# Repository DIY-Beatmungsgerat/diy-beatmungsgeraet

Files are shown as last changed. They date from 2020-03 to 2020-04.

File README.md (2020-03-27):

<p align="center">
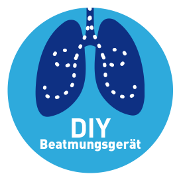
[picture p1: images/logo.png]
  
</p>

# DIY-Beatmungsgerät

DIY Beatmungsgerät basierend auf einem Open Source und Open Hardware Entwurf. Der Grundstein wurde während des [#WirvsVirusHackathon](https://wirvsvirushackathon.org/) im März 2020 gelegt.

Momentan sind wir noch mitten im Endspurt des Wochenendes, daher wird es noch eine Weile dauern, bis dieses Repository tatsächlich mit unseren Inhalten gefüllt ist. Derzeit pflegen wir unsere Inhalte noch intern ein!

Das 3D-Modell des Beatmungsgerätes basiert auf Iteration #6 des Open Source Ventilator (OSV) Project, in gitlab unter https://gitlab.com/open-source-ventilator/OpenLung zu finden.

(eventuell wechseln wir die Dokumentation hier auf Englisch)

## Repository-Struktur

Wir arbeiten an verschiedensten Themen. Zum einen etwa an der Weiterentwicklung des Beatmungsgerätes, als auch an dessen Ansteuerung bzw. Regelung und weiterer Sensorik.

* [/ hardware / mass-airflow-model /](/hardware/mass-airflow-model/): Modelle für die Röhre eines Masseflusssensors
* [/ hardware / ventilator-model/](/hardware/ventilator-model/): das weiterentwickelte Modell des Beatmungsgerätes
* [/ software / mass-airflow-sensor / controller-software/](/software/mass-airflow-sensor/controller-software/): die Software, die auf der Plattform läuft, um den Luftmassesensor auszulesen (Mock-Up)
* [/ software / mass-airflow-sensor / sensor-software/](/software/mass-airflow-sensor/sensor-software/): die Software, die auf dem Sensor selbst läuft, der Luftmassesensor-Daten bereitstellt (Mock-Up)
* [/ software / ventilator-control/](/software/ventilator-control/): die Software für die Steuerungs-Plattform des Beatmungsgerätes

# Weiterführende Links
* [Homepage des WirvsVirus Hackathon](https://wirvsvirushackathon.org/)
* [Projekt-Vorstellung auf devpost.com](https://devpost.com/software/diy-beatmungsgerat)
* [Projekt-Vorstellung auf YouTube](https://www.youtube.com/watch?v=DzOd6LIBdXI)
* https://gitlab.com/open-source-ventilator/OpenLung

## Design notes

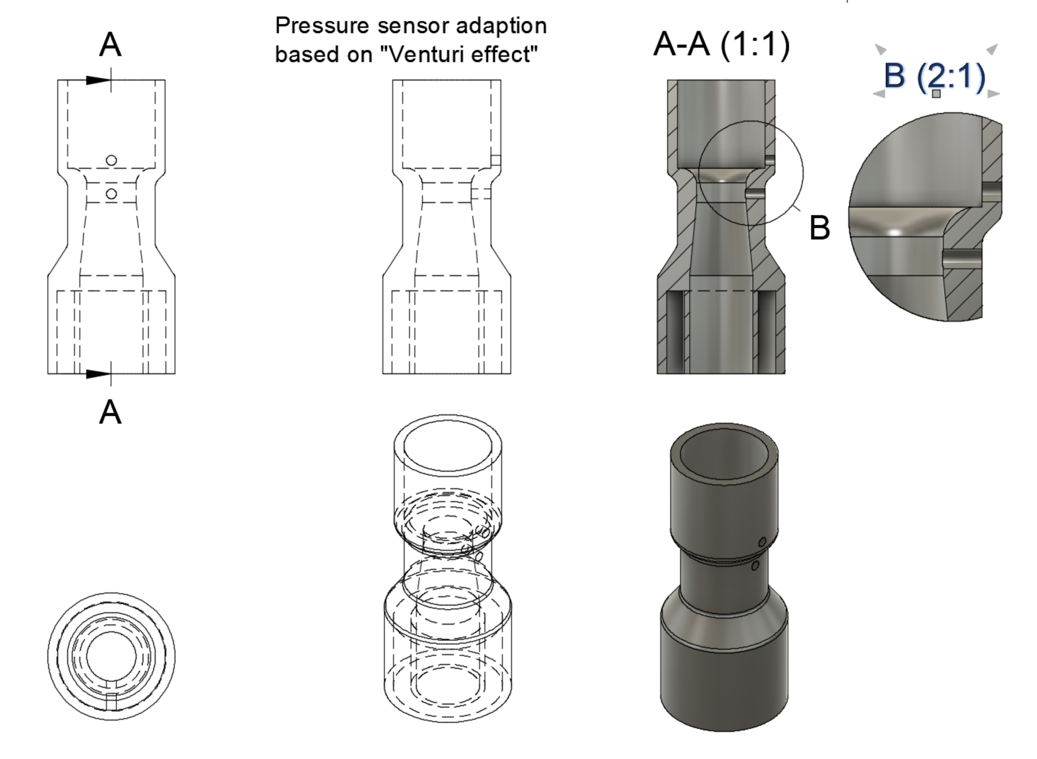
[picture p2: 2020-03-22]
images/mass_airflow_adapter_drawing.png

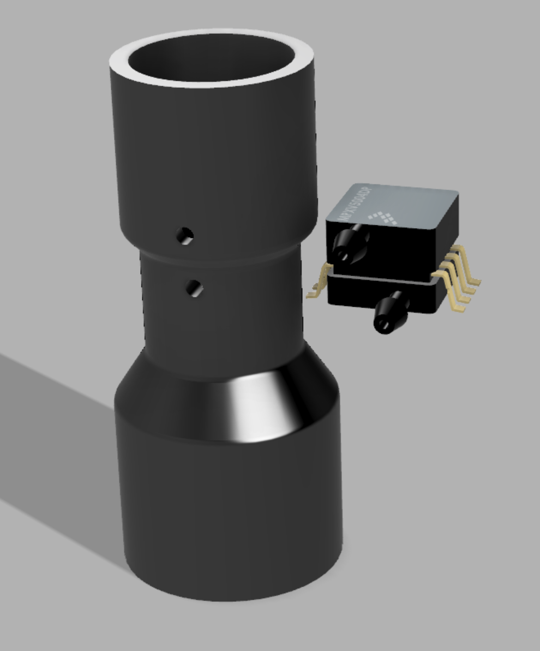
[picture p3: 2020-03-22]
images/mass_airflow_adapter_with_sensor.png

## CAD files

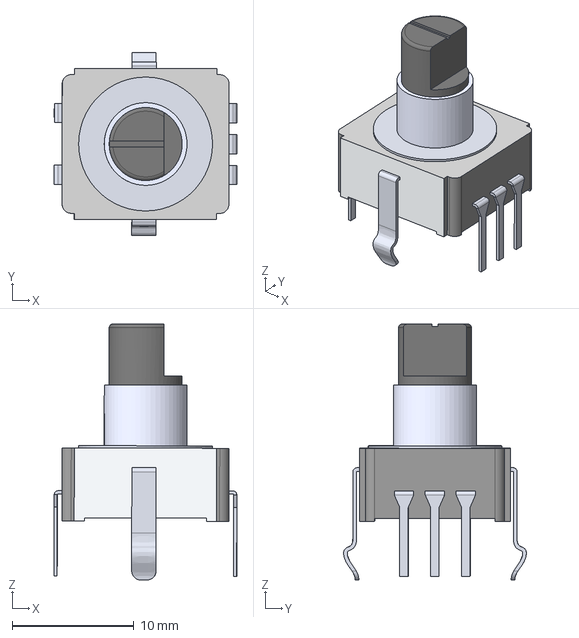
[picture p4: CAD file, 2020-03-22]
hardware/ventilator-model/Encoder v2.step
15.0 x 15.0 x 21.0 mm

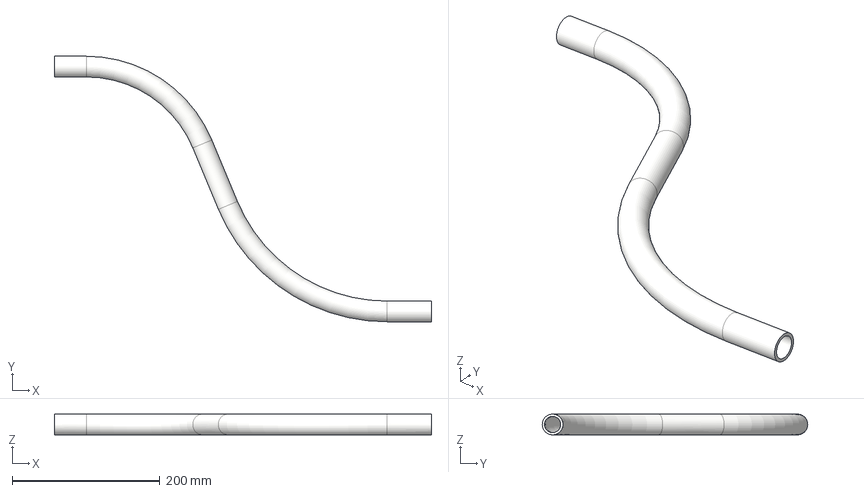
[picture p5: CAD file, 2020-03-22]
hardware/ventilator-model/Schlauch v5.step
510.0 x 359.2 x 28.0 mm

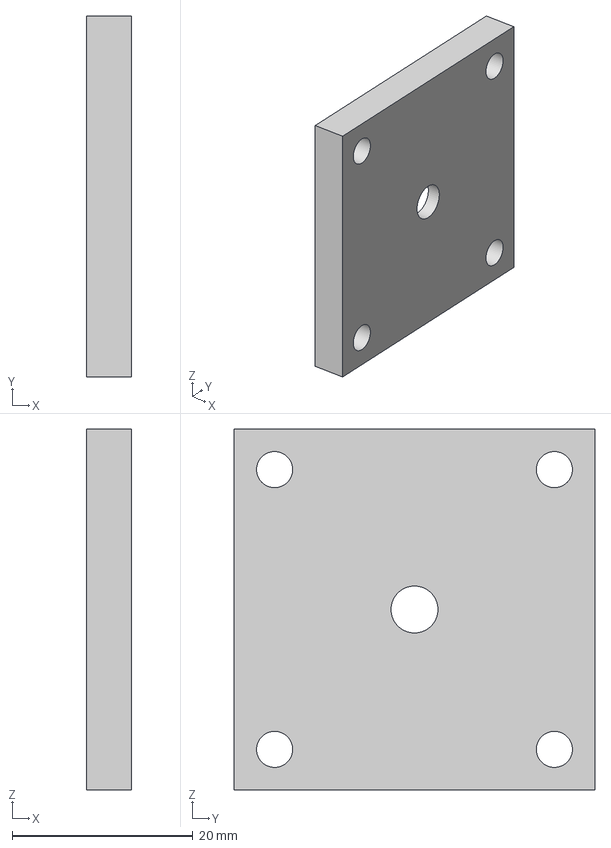
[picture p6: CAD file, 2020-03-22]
hardware/ventilator-model/Encoderplatte v2.step
5.00 x 40.0 x 40.0 mm

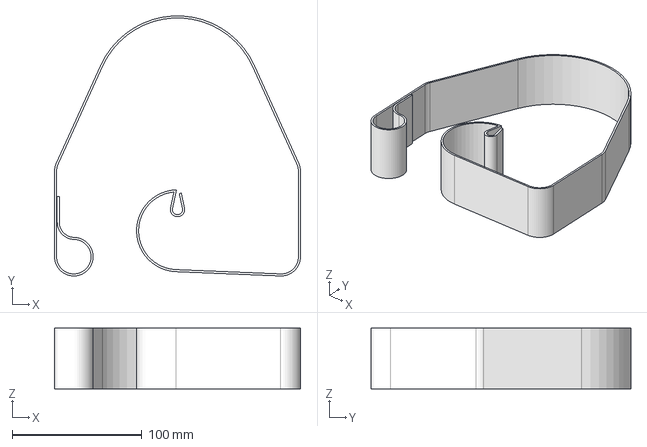
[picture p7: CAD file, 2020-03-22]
hardware/ventilator-model/Belt v1.step
189.8 x 200.6 x 47.0 mm

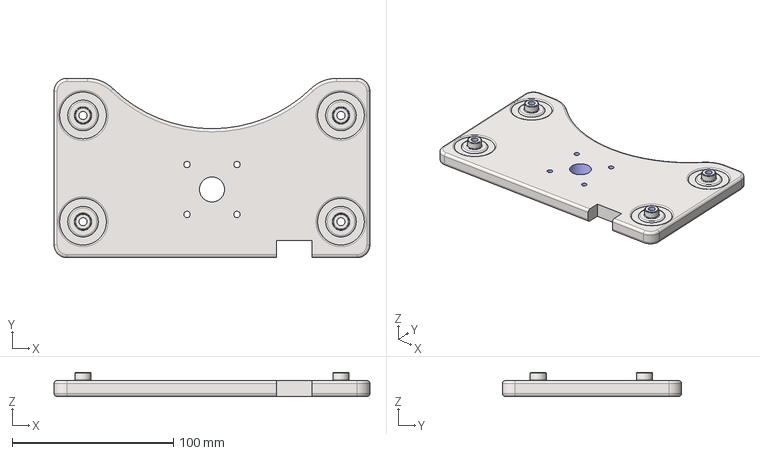
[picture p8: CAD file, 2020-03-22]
hardware/ventilator-model/HousingMotor v2.step
196.0 x 111.2 x 15.0 mm

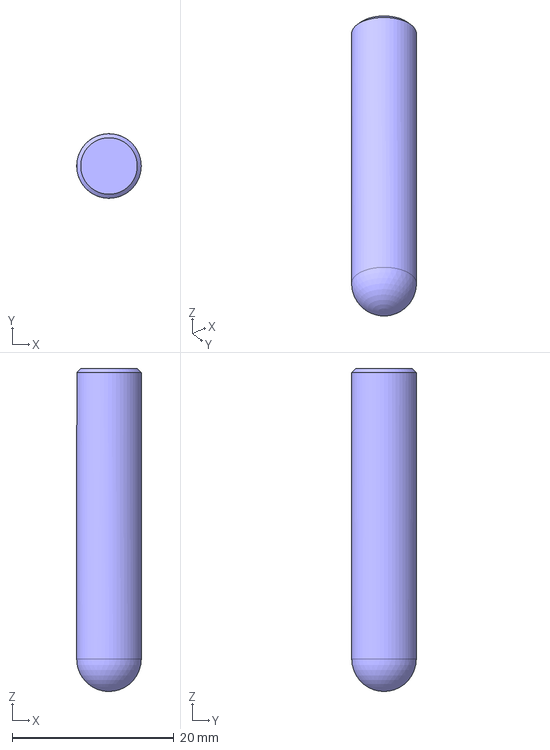
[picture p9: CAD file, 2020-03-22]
hardware/ventilator-model/Pin v1.step
8.00 x 8.00 x 40.0 mm

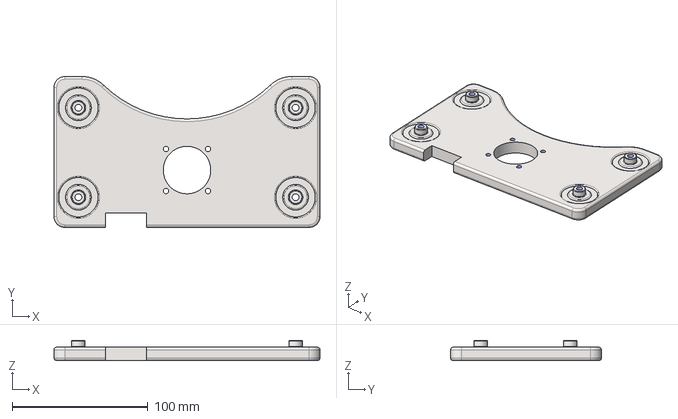
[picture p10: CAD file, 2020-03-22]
hardware/ventilator-model/HousingElectrical v3.step
196.0 x 111.2 x 15.0 mm

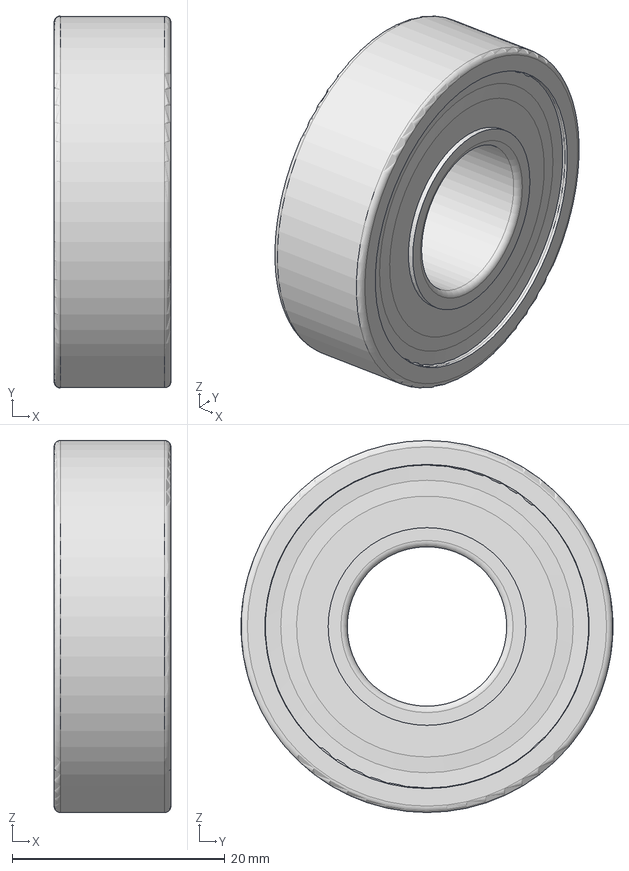
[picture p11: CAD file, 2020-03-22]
hardware/ventilator-model/Rillenkugellager_15x35x11 v1.step
11.0 x 35.0 x 35.0 mm
_6202-2RSL_PART1
_6202-2RSL_PART2
_6202-2RSL_PART3 x 8
_6202-2RSL_PART4 x 8

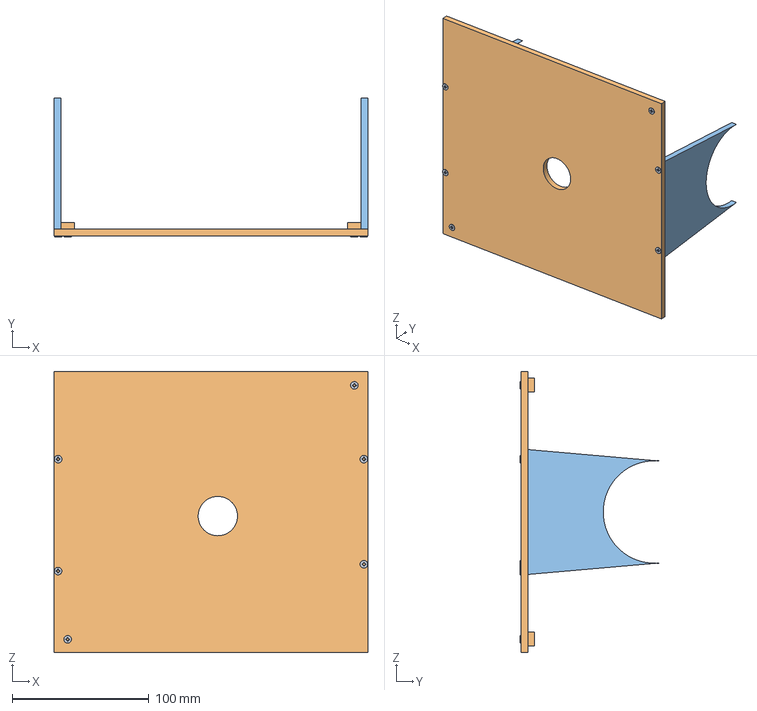
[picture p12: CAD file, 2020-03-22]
hardware/ventilator-model/Deckel v6.step
230.0 x 101.6 x 206.0 mm
DIN 7997 H - d 3 x l 10 - St x 6

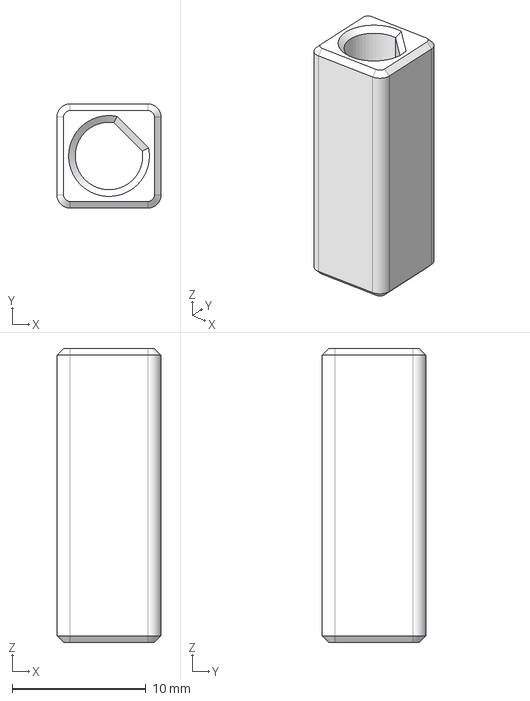
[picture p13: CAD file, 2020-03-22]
hardware/ventilator-model/ShaftAdaptor v1.step
7.80 x 7.80 x 22.0 mm

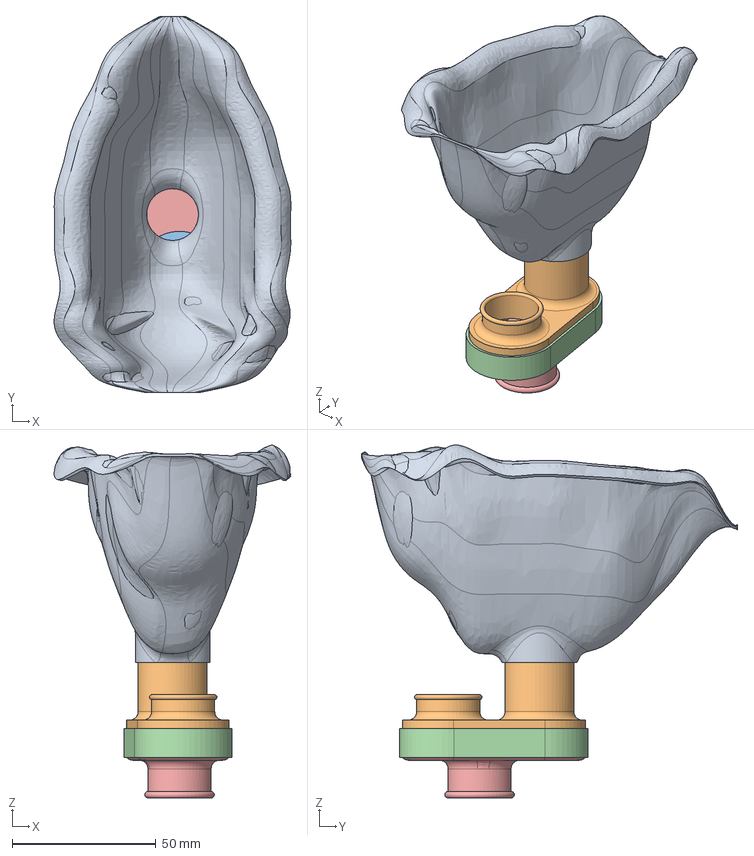
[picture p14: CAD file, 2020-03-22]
hardware/ventilator-model/Maske v1.step
82.5 x 131.0 x 123.0 mm
medical mask
BODY VALVE
flap
BODY VALVE 1

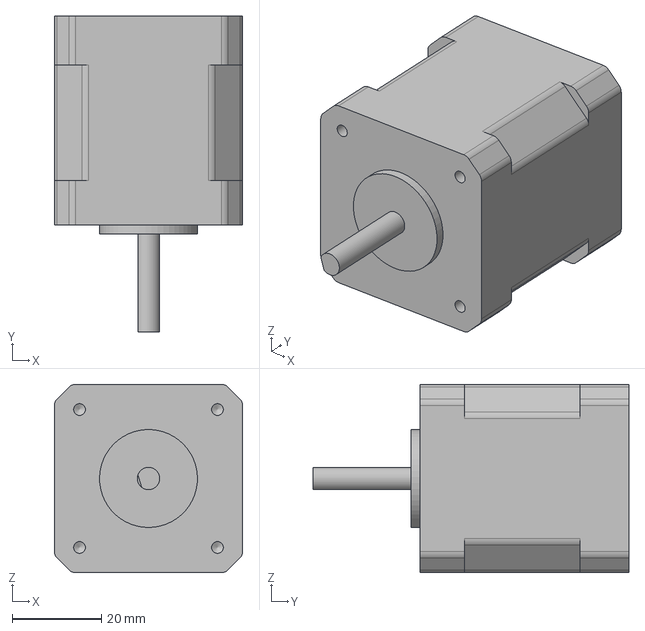
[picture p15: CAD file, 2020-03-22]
hardware/ventilator-model/StepMotor_Nema17 v1.step
42.3 x 71.0 x 42.3 mm

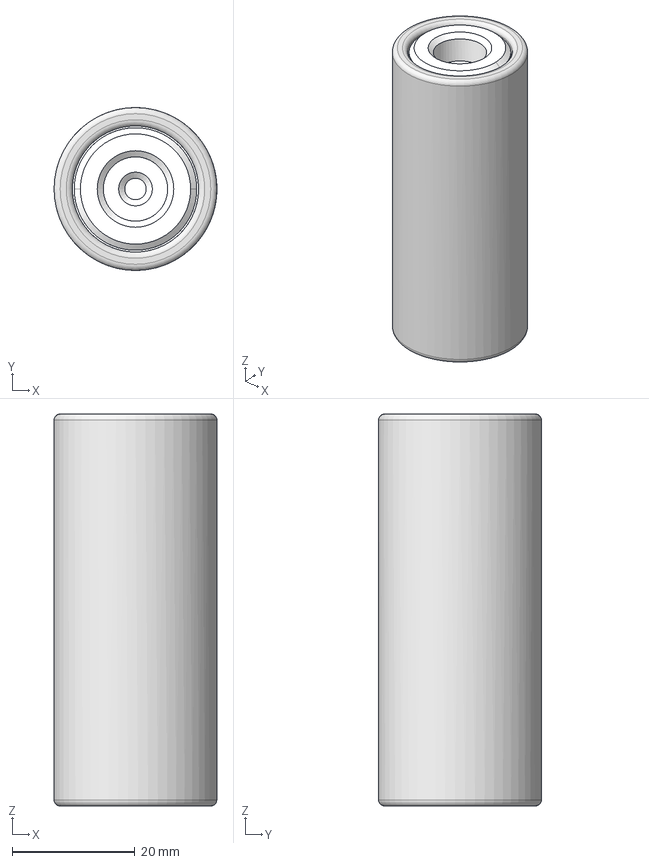
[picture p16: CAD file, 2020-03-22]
hardware/ventilator-model/Spacer v3.step
26.6 x 26.6 x 64.0 mm

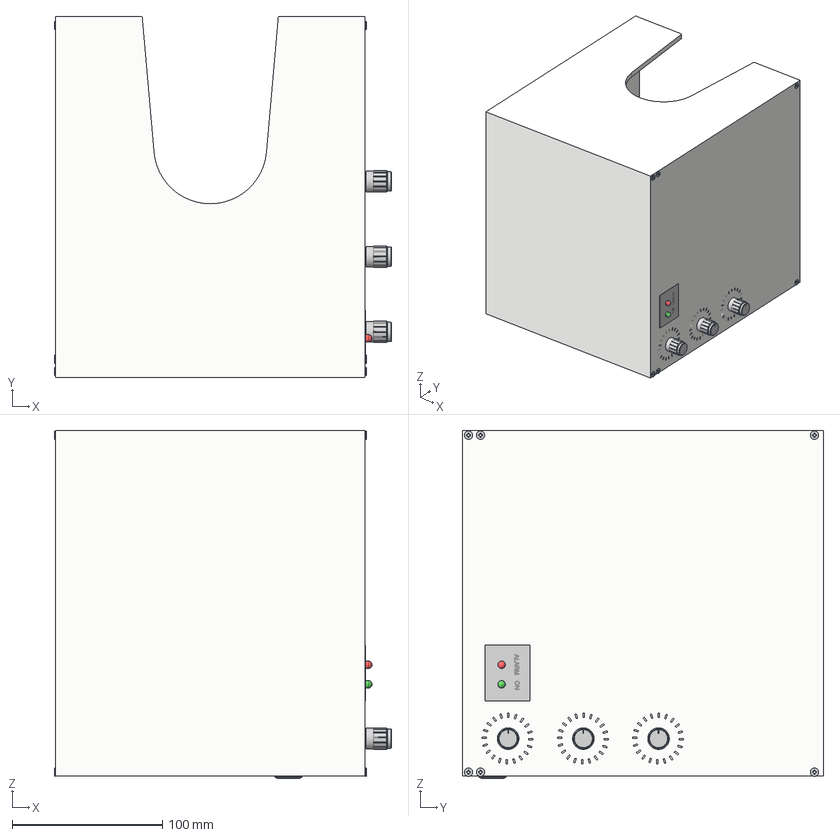
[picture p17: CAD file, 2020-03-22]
hardware/ventilator-model/Gehaeuse v31.step
224.4 x 240.0 x 231.7 mm
DIN 7997 H - d 3 x l 10 - St x 12
Poti x 3
Pot Knob x 3
ONOFFswitch
LED 5mm Red
LED 5mm Green

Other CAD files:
hardware/ventilator-model/Roller v2.step
hardware/ventilator-model/DIN7049-ST4 v1.step
hardware/mass-airflow-model/MPXV5004DP_3D.f3d
hardware/mass-airflow-model/mass_airflow_tube.f3d

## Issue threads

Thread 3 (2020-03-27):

Aktuelles Riemen-Design verursacht Drehung des / Reibung am BVM

joernhees, 2020-03-27:
Momentan sieht das Design so aus und wird entweder zu einer Drehung des BVMs oder viel Reibung und schnellem Verschleiß an diesem führen

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

Mein Vorschlag wäre das Design leicht zu verändern, indem der Riemen auch auf der anderen Seite um den Roller gelegt wird:
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

Auf die Weise wird der Riemen oben nur angezogen und rollt den BVM nicht mehr hin und her.

Bei der Änderung würde ich die Einschnitte im Roller für die Riemen-Enden auch gleich nicht so tief machen, damit er stabiler wird.

Leider konnte ich die step-files nicht einfach anpassen, daher hier nur als Konzept.

FelixThe, 2020-03-28:
Hört sich sinnvoll an

mechprof, 2020-03-30:
Hallo Zusammen,

ich bin Mechanik Entwickler und im Automobilbereich tätig. Ich habe am WE Euer Projekt entdeckt, unter anderem auch das Thema hier. Ich finde die Idee mit dem Riemen super genial. Die Abmessungen im CAD entsprechen fast genau den üblichen eines Anschnallgurtes im Auto. Das ist eine super Idee, Anschnallgurte sind sehr robust und weltweit verfügbar und völlig überdiemensioniert. Dh. die halten ewig.

Wenn Ihr offen seit, würde ich gerne einen optimierten Vorschlag als step hochladen. Was haltet Ihr von einem parallelen Verzeichnis. Seit Ihr damit einverstanden?

meine Optimierungsaspekte:

- die Antriebsrolle kann verkleinert werden => Ziel d=16mm, da doppelte Aufwicklung 16*pi*2 je Umdrehung. Achtung: 1,5 bis 2 Umdrehungen sollten minimum immer drauf sein. Da Archimedische Spirale wird d je Umdrehung 4 Gurtlagen dicker.
- höhere Teileintegration
- reduzierte Teile Zahl => Fertigungsaufwand / -kosten => Teile die es nicht gibt gehen nicht kaputt
- geringeres 3d print volumen => weniger Bauzeit
- Robustheit a) Teile b) Montage c) Funktion
- Trennung der Bauräume:
   - mechanische Komponenten (beweglich)
   - elektromechanische Komponenten (Motor)
   - elektrische Komponenten (Platine, Poti, LEDs, ...) => Ziel: staubfrei, Druck-/Feuchteausgleich

Falls jemand die Software Apis zur Verfügung hat, ich bin gerne bereit mit der Person eine FMEA aufzusetzen.

Anregungen:
   - Positionsmarkierungen auf Gurt (weisse Streifen, ein breiter Streifen als Referenz irgendwo in der Mitte), damit Entfall elektromechanisches Bauteil Encoder => Kontaktlose, verschleissfreie Positionserkennung. Können mit weissem Edding aufgemalt werden, Mit Laser ausgedruckt und auf Gurt genäht oder geklebt werden, wie auch immer....

Bitte:
Dies ist meine erste Github Benutzung. Sagt mir einfach was ich besser machen soll. Gebt mir einen Link wo es kurz und knapp schon steht. Ich habe einfach keine Ahnung.
  -

mechprof, 2020-03-30:
Hier ist mein aktueller Arbeitsstand in Bildern.

erreichte Ziele:
- alles auf einer Platine integriert: nur noch Motor und on/off Schalter mit Kabel
- Funktionen siehe Screenshot Stückliste

Frage:
- wofür braucht es den Massenstromsensor?
- das zugeführte Volumen ergibt sich aus p*v=R*T, wobei p und T via BME680 gemessen werden und v mit dem displacement korreliert und nach experimenteller Feststellung des Zusammenhangs gut ermittelt werden kann.

Es wäre sehr nett, wenn wir hier im Dialog weiter kämen. Ich hoffe anhand der Bilder wird klar, dass ich hier etwas beitragen kann.

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

mechprof, 2020-04-01:
**OK, verstanden, dass Projekt hier scheint tot zu sein.
Falls jemand weiter machen möchte, einfach melden.

Schlecht ist die Idee nicht.**

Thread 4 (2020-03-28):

Möglich Bewegung an den Schläuchen kann zu Abnutzung führen / Potential wear on hoses could lead to wear

FelixThe, 2020-03-28:
Im aktuellen Konzept wird der Beatmungsbeutel nur von einer Seite gedrückt (links). Dies kann zu einer Bewegung an den Schläuchen führen. Was haltet ihr davon, den Beutel von zwei Seiten zu drücken (rechts)? Dadurch würden sich die Schläuche weniger relativ zum Gehäuse bewegen.

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

mattheiss2020, 2020-03-28:
It looks like a nice solution, but I just remember my physics class at school and I think that we would need quite a strong motor to be able to squeeze the Ambu bag? Can anybody calculate that?

FelixThe, 2020-03-28:
Yes, you are right! It would need higher forces to squeeze the bag. I will think about a different solution for squeezing the bag from two sides.

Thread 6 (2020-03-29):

Abgleich mit MIT-Projekt

aKzenT, 2020-03-29:
https://e-vent.mit.edu/

Möglicherweise kann man sich von dort ja die ein oder andere Idee abschauen oder sich mit dem Team dort vernetzen, wenn noch nicht geschehen.

Heavy02011, 2020-03-30:
Vielen Dank, ja wir pflegen eine Liste der weiteren Projekte und ich werde ihm Team vorschlagen, dass sich darum jemand kümmert.

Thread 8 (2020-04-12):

Add GitHub workflow to validate code compilation in CI

synergiator, 2020-04-12:
Using for example Arduino CLI, it's possible to validate code compilation online without having the actual board.

See also:

https://codeblog.dotsandbrackets.com/gitlab-ci-esp32-arduino/

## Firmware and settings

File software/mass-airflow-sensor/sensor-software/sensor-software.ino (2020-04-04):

#include <Wire.h>
#include "crc8.h"

// Test setup:
//   Arduino Nano pin asssignment:
//     I2C SDA:      A4
//     I2C SCL:      A5
//     Analog input: A0
//     Real-time supervision pin: A3
//     Interrupt supervision pin: A2

/* Mapping of the analog input pin, define alias here */
#define ANALOG_INPUT_PIN      (A0)

/* Mapping of the digital output pin for real-time supervision, define alias here */
#define RT_SUPERVISION_PIN    (A3)

/* Mapping of the digital output pin for interrupt supervision, define alias here */
#define INT_SUPERVISION_PIN   (A2)

//#define DEBUG
#ifdef DEBUG
    #define debugPrint    Serial.print
    #define debugPrintln  Serial.println
#else
    #define debugPrint    
    #define debugPrintln  
#endif

/* Definition of sensor loop interval and loop delay,
 * i.e. how often to read the ANALOG_INPUT_PIN in order to get a new measurement from sensor;
 * the value is given in milliseconds.
 * current setting: approx. every 10 ms (i.e. at a rate of 100 Hz).
 * Note: This is not exact as the UART serial output will take some of that time, 
 *       plus conversions and interrupt overhead, plus loop overhead.
 *       When DEBUG output is active, it takes about 2 ms per cycle.
 *       Caution: The interrupt overhead is not subtracted automatically.
 */
#define SENSOR_LOOP_INTERVAL (10u)
#ifdef DEBUG
    #define SENSOR_LOOP_DELAY (SENSOR_LOOP_INTERVAL - (2u))
#else
    #define SENSOR_LOOP_DELAY (SENSOR_LOOP_INTERVAL)
#endif

/* Definition of sensor modes, i.e. what values will be return upon Wire transmit request event */
enum eSensorMode { SENSOR_MODE_NONE = 0, SENSOR_MODE_MEASURE, SENSOR_MODE_SERIALNO };

/* define the address of the sensor on the I2C bus;
 * TODO/FIXME: decide address to be used via GPIO input pin during setup()
 */
uint8_t g_nDeviceAddress = 64;

/* Initialize global variables */
//volatile int g_nConversionValue = 0; /* digital value for sensor's analog input */
volatile eSensorMode g_eMode = SENSOR_MODE_NONE; /* sensor mode start with 'NONE' */

volatile int16_t g_nDiffPressure = 0;

void setup()
{
    Serial.begin(230400);         // start serial for debug output

    Wire.begin(g_nDeviceAddress); // join i2c bus with address <g_nDeviceAddress>
    Wire.onReceive(receiveEvent); // register event handler for Rx
    Wire.onRequest(transmitRequestEvent); // register event handler for Tx request

#ifdef RT_SUPERVISION_PIN
    pinMode(RT_SUPERVISION_PIN, OUTPUT);
#endif
#ifdef INT_SUPERVISION_PIN
    pinMode(INT_SUPERVISION_PIN, OUTPUT);
#endif

#ifdef DEBUG
    Serial.println("Debug mode active.");
#else
    Serial.println("Debug mode inactive, no more output on serial.");
#endif
}

void loop()
{
    static int nConversionValue = 0;

#ifdef RT_SUPERVISION_PIN
    digitalWrite(RT_SUPERVISION_PIN, HIGH);
#endif
    
    nConversionValue = analogRead(ANALOG_INPUT_PIN);

    if( SENSOR_MODE_MEASURE == g_eMode )
    {
        debugPrint("[*] "); /* in measuring mode */
    }
    else
    {
        debugPrint("[ ] "); /* not in measuring mode */
    }

    // Debug output the sensor's reading (conversion valie)
    debugPrint("Sensor value: ");

    debugPrint(nConversionValue); // raw reading
    debugPrint(" counts, ");

    debugPrint( countsToMillivolts(nConversionValue) );
    debugPrint(" mV, ");

    float fPressure = millivoltsToMillimetersWater( countsToMillivolts( nConversionValue ) );
    debugPrint( fPressure );
    debugPrint(" mmH2O, ");

    g_nDiffPressure = ((int16_t)fPressure) << 2; /* the two least-significant bits are always zero */
    debugPrint( g_nDiffPressure );
    debugPrintln(" mmH2O*4");

    /* TODO/FIXME: add conversion from difference pressure to volume flow */

#ifdef RT_SUPERVISION_PIN
    digitalWrite(RT_SUPERVISION_PIN, LOW);
#endif

    /* Wait until next cyclic measurement is made */
    delay(SENSOR_LOOP_DELAY);
}

crc_t calcCrc(const unsigned char *pData, size_t nDataLen)
{
    crc_t nCrc = crc_init();
    nCrc = crc_update(nCrc, pData, nDataLen);
    nCrc = crc_finalize(nCrc);

    return nCrc;
}

/* Parse received command and switch sensor's state */
void receiveEvent(int nBytes)
{
    char sHexBuf[11]; /* string buffer for debug output via UART */
    uint8_t cCmdBytes[2]; /* command buffer (a command is 16 bit wide, or 2 bytes) */
    int nRxCount = 0;

#ifdef INT_SUPERVISION_PIN
    digitalWrite(INT_SUPERVISION_PIN, HIGH);
#endif

    debugPrint("Rx (");
    debugPrint(nBytes);
    debugPrint(" bytes): ");
    while(0 < Wire.available())   // loop through all but the last
    {
        uint8_t cRxByte = Wire.read(); /* receive byte as a character */

        /* store first two bytes in command buffer */
        if( nRxCount < 2 )
        {
            cCmdBytes[nRxCount] = cRxByte;
        }
        
        nRxCount++;

        /* print every byte as two hex digits with prefix '0x', NULL-terminate the string */
        sprintf(sHexBuf, "0x%02X ", cRxByte);
        sHexBuf[5] = 0;
        debugPrint(sHexBuf);
    }
    debugPrintln("");

    if( nRxCount < 2 )
    {
#ifdef INT_SUPERVISION_PIN
        digitalWrite(INT_SUPERVISION_PIN, LOW);
#endif
        return;
    }

    if( nRxCount != nBytes )
    {
        debugPrint("[DEBUG] Message length does not match (Rx count: ");
        debugPrint(nRxCount);
        debugPrint("; Message length: ");
        debugPrint(nBytes);
        debugPrintln(")");
        g_eMode = SENSOR_MODE_NONE;
#ifdef INT_SUPERVISION_PIN
        digitalWrite(INT_SUPERVISION_PIN, LOW);
#endif
        return;
    }

    if( 0x10 == cCmdBytes[0] && 0x00 == cCmdBytes[1] )
    {
        debugPrintln("Rx'ed 'start measurement' command");
        g_eMode = SENSOR_MODE_MEASURE;
    }
    else if( 0x31 == cCmdBytes[0] && 0xAE == cCmdBytes[1] )
    {
        debugPrintln("Rx'ed 'read serial number' command");
        g_eMode = SENSOR_MODE_SERIALNO;
    }
    else
    {
        debugPrintln("Rx'ed unknown command: ");
        sprintf(sHexBuf, "0x%02X 0x%02X ", cCmdBytes[0], cCmdBytes[1]);
        sHexBuf[10] = 0;
        debugPrint(sHexBuf);
        
        debugPrintln("(ignored)");
    }

#ifdef INT_SUPERVISION_PIN
        digitalWrite(INT_SUPERVISION_PIN, LOW);
#endif
}

/* Transmit data dependent on current sensor state */
void transmitRequestEvent(void)
{
#ifdef INT_SUPERVISION_PIN
    digitalWrite(INT_SUPERVISION_PIN, HIGH);
#endif

    debugPrintln("Tx request");

    switch( g_eMode )
    {
        case SENSOR_MODE_MEASURE:
            /* TODO/FIXME: add true measurement data and add CRC */
            debugPrintln("Tx measurement");
            char sMeas[2];
            //sMeas[0] = 'F';
            //sMeas[1] = 'L';
            sMeas[0] = (uint8_t)( (g_nDiffPressure & 0xFF00) >> 8 );
            sMeas[1] = (uint8_t)(g_nDiffPressure & 0xFF);
            Wire.write((char)sMeas[0]);
            Wire.write((char)sMeas[1]);
            Wire.write((char)calcCrc(&sMeas[0], 2) );
            break;
        case SENSOR_MODE_SERIALNO:
            char sSerNo[4];
            sSerNo[0] = 'S';
            sSerNo[1] = 'R';
            sSerNo[2] = 'N';
            sSerNo[3] = 'O';
            debugPrintln("Tx serialno");
            Wire.write((char)sSerNo[0]);
            Wire.write((char)sSerNo[1]);
            Wire.write((char)calcCrc(&sSerNo[0], 2) );
            Wire.write((char)sSerNo[2]);
            Wire.write((char)sSerNo[3]);
            Wire.write((char)calcCrc(&sSerNo[2], 2) );
            break;
        case SENSOR_MODE_NONE:
        default:
            debugPrintln("Tx nothing (controller will read 0xFF)");
            break;
    }

#ifdef INT_SUPERVISION_PIN
        digitalWrite(INT_SUPERVISION_PIN, LOW);
#endif
}

float countsToMillivolts(int nCounts)
{
    // For the Arduino Uno, its a 10 bit unsgined value (i.e. a range of 0..1023).
    // Its measurement range is from 0..5 volts.
    // This yields a resolution between readings of: 5 volts / 1024 units or approx. 4.9 mV per LSB
    return nCounts * 4.882813f;
}

float millivoltsToMillimetersWater(float fMillivolts)
{
    // for now, assume a linear transfer function of the sensor,
    // e.g. V_out = 0.6 V/kPa * dP + 0.6 V
    //         dP = (V_out - 0.6 V) / 0.6 V/kPa 
    //            = (V_out - 0.6 V) * 1.667 kPa/V
    //            = (V_out - 600 mV) * (1.667*100 mmH2O) / 1000 mV // 1 kPa ~ approx. 100 mmH2O

    float fPressure = (fMillivolts - 600.0f) * 0.1666666667f;

    // sanity check: no negative pressure value
    fPressure = (fPressure < 0.0f) ? 0.0f : fPressure;
    
    return fPressure;
}

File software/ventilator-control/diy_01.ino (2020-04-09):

#Disclaimer "This is not a medical device and it must not be used in a clinical environment."

#include <ESP8266WiFi.h>
#include <BlynkSimpleEsp8266.h>
#include <Wire.h>
#include <Adafruit_MotorShield.h>
#include <Encoder.h>
#include <bsec.h>
#include <Ticker.h>

String matrixausgabe_text  = " "; // Ausgabetext als globale Variable

volatile int matrixausgabe_index = 0;// aktuelle Position in Matrix

int breathcycle = 0 ;
int breathpause = 0 ;
int speed = 0 ;
bool start= false ;
int humdity = 0 ;
int volumen = 0 ;
// Feather Adafruit Motor Shield v2 http:\www.adafruit.com/products/1438
Adafruit_MotorShield AFMS = Adafruit_MotorShield(); // Treiber-Objekt
Adafruit_StepperMotor *myStepMotor1 = AFMS.getStepper(100,1); // Motor 1-Objekt, 100 Steps/Umdrehung
Adafruit_StepperMotor *myStepMotor2 = AFMS.getStepper(100,2); // Motor 2-Objekt
// Control Feather Motor Shield
void setMotorSteps(int mot, int steps, int speed) {
  int dir= RELEASE; 	
  if (steps > 0)
    dir = FORWARD;
  else {
    dir = BACKWARD;
    steps = - steps;
  }
  switch (mot) {
  case 1:
    myStepMotor1->setSpeed(speed);
    myStepMotor1->step(steps, dir, DOUBLE);
    if (steps==0) myStepMotor1->release();
    break;
  case 2:
    myStepMotor2->setSpeed(speed);
    myStepMotor2->step(steps, dir, DOUBLE);
    if (steps==0) myStepMotor2->release();
    break;
  }
}

// Encoder-Library http://www.pjrc.com/teensy/td_libs_Encoder.html
Encoder button_encoder(14,12); // Objekt Dreh-Encoder
/* 
 Bosch BSEC Lib, https://github.com/BoschSensortec/BSEC-Arduino-library
 The BSEC software is only available for download or use after accepting the software license agreement.
 By using this library, you have agreed to the terms of the license agreement: 
 https://ae-bst.resource.bosch.com/media/_tech/media/bsec/2017-07-17_ClickThrough_License_Terms_Environmentalib_SW_CLEAN.pdf */
Bsec iaqSensor;     // Create an object of the class Bsec 
Ticker Bsec_Ticker; // schedule cyclic update via Ticker 

// ------------------------   Helper functions Bosch Bsec - Lib 
void checkIaqSensorStatus(void)
{ 
  String output; 
  if (iaqSensor.status != BSEC_OK) {
    if (iaqSensor.status < BSEC_OK) {
      output = "BSEC error code : " + String(iaqSensor.status);
      for (;;) {
        Serial.println(output);
        delay(500);
      } // Halt in case of failure 
    } 
    else {
      output = "BSEC warning code : " + String(iaqSensor.status);
      Serial.println(output);
    }
  }

  if (iaqSensor.bme680Status != BME680_OK) {
    if (iaqSensor.bme680Status < BME680_OK) {
      output = "BME680 error code : " + String(iaqSensor.bme680Status);
      for (;;){
        Serial.println(output);
        delay(500);
      }  // Halt in case of failure 
    } 
    else {
      output = "BME680 warning code : " + String(iaqSensor.bme680Status);
      Serial.println(output);
    }
  }
}

// Housekeeping: scheduled update using ticker-lib
void iaqSensor_Housekeeping(){  // get new data 
  iaqSensor.run();
}

int pressure = 0 ;
int co2 = 0 ;
int heardbeat = 0 ;
int spo2 = 0 ;
int heartbeat = 0 ;


void setup(){ // Einmalige Initialisierung
  Serial.begin(115200);
  Serial.println();
  Wire.begin(); // ---- Initialisiere den I2C-Bus 

  if (Wire.status() != I2C_OK) Serial.println("Something wrong with I2C");

  AFMS.begin(); // Setup Feather-Shield 1.6KHz PWM

  Wire.setClock(400000L); // speed up i2c 
  iaqSensor.begin(BME680_I2C_ADDR_PRIMARY, Wire);
  String output = "\nBSEC library version " + String(iaqSensor.version.major) + "." + String(iaqSensor.version.minor) + "." + String(iaqSensor.version.major_bugfix) + "." + String(iaqSensor.version.minor_bugfix);
  Serial.println(output);
  checkIaqSensorStatus();

  bsec_virtual_sensor_t sensorList[10] = {
    BSEC_OUTPUT_RAW_TEMPERATURE,
    BSEC_OUTPUT_RAW_PRESSURE,
    BSEC_OUTPUT_RAW_HUMIDITY,
    BSEC_OUTPUT_RAW_GAS,
    BSEC_OUTPUT_IAQ,
    BSEC_OUTPUT_STATIC_IAQ,
    BSEC_OUTPUT_CO2_EQUIVALENT,
    BSEC_OUTPUT_BREATH_VOC_EQUIVALENT,
    BSEC_OUTPUT_SENSOR_HEAT_COMPENSATED_TEMPERATURE,
    BSEC_OUTPUT_SENSOR_HEAT_COMPENSATED_HUMIDITY,
  };

  iaqSensor.updateSubscription(sensorList, 10, BSEC_SAMPLE_RATE_LP);
  checkIaqSensorStatus();  
  iaqSensor_Housekeeping();
  Bsec_Ticker.attach_ms(2000, iaqSensor_Housekeeping);

  randomSeed(analogRead(A0) + analogRead(A0) + analogRead(A0));
  pinMode( 15 , OUTPUT);
  //------------ WLAN initialisieren 
  WiFi.persistent(false);
  WiFi.mode(WIFI_STA);
  delay(100);
  Serial.print ("\nWLAN connect to:");
  Serial.print("your ssid");
  WiFi.begin("your ssid","your pwd");
  while (WiFi.status() != WL_CONNECTED) { // Warte bis Verbindung steht 
    delay(500); 
    Serial.print(".");
  };
  Serial.println ("\nconnected, meine IP:"+ WiFi.localIP().toString());
  matrixausgabe_text = " Meine IP:" + WiFi.localIP().toString();
  matrixausgabe_index=0;

  Blynk.config("key","blynk-cloud.com",80);// Downloads, docs, tutorials: http://www.blynk.cc
  int BlynkCon = 0;
  while (BlynkCon == 0) {
    Serial.print ("\nBlynk connect ... ");
    BlynkCon=Blynk.connect();
    if (BlynkCon == 0) {
      Serial.println("failed, try again");
      delay(1000);
    }
  }
  Serial.println("connected");

  breathcycle = 7000 ;

  breathpause = 3500 ;

  speed = 50 ;

  start = LOW ;

}

void loop() { // Kontinuierliche Wiederholung 
  Blynk.run();// Blynk Housekeeping
  readsensor();
  senddata();
  if (( ( ( humdity ) > ( 60 ) ) && start ))
  {
    Serial.print("Beatmung start - Volumen:"+String(String(volumen)));
    Serial.println();
    delay( 250 );
    setMotorSteps(1,volumen,speed);    // Ausgabe an Motor 
    delay( breathpause );
    setMotorSteps(1,( volumen * -1 ),speed);    // Ausgabe an Motor 
    delay( 250 );
  }
}

void readsensor()
{
  volumen = button_encoder.read() ;
  humdity = iaqSensor.humidity ;
  pressure = (iaqSensor.pressure/100.) ;
  co2 = iaqSensor.co2Equivalent ;
  heardbeat = ( 70 + 	random( 20 ) ) ;
  spo2 = ( 99 - 	random( 20 ) ) ;
  if (digitalRead(2)==LOW)
  {
    start = HIGH ;
  }
  Serial.print("Volumen:"+String(String(volumen)));
  Serial.println();
  Serial.print("Start:"+String(String(start)));
  Serial.println();
  checkalarm();
}

void senddata()
{
  Blynk.virtualWrite(1,volumen);// Wert an Blynk-Server übermitteln
  Blynk.run();// Blynk Housekeeping
  Blynk.virtualWrite(2,humdity);// Wert an Blynk-Server übermitteln
  Blynk.run();// Blynk Housekeeping
  Blynk.virtualWrite(3,pressure);// Wert an Blynk-Server übermitteln
  Blynk.run();// Blynk Housekeeping
  Blynk.virtualWrite(4,co2);// Wert an Blynk-Server übermitteln
  Blynk.run();// Blynk Housekeeping
  Blynk.virtualWrite(5,heardbeat);// Wert an Blynk-Server übermitteln
  Blynk.run();// Blynk Housekeeping
  Blynk.virtualWrite(6,spo2);// Wert an Blynk-Server übermitteln
  Blynk.run();// Blynk Housekeeping
  Blynk.virtualWrite(7,start);// Wert an Blynk-Server übermitteln
  Blynk.run();// Blynk Housekeeping
}
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

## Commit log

2020-03-22 Add files via upload
    Gesamtkonzept_v19 ist die Gesamtbaugruppe
    [Belt v1.step, DIN7049-ST4 v1.step, Deckel v6.step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]
2020-03-23 Added mock-up code for sensor software and controller software (initial communication test)
2020-03-23 Added reading and vonversion of analog input values in mass airflow sensor code
2020-03-26 Added more mock-up code for the flow sensor/meter and its controller
2020-03-27 Succesfull mass airflow sensor communication ping-pong
2020-03-27 Improved sensor and sensor controller code of mass airflow sensor
2020-03-28 Added CRC in mass airflow sensor code, fixed minor bugs
    [controller-software.ino, sensor-software.ino]
2020-03-28 Fixed minor bugs in mass airflow sensor code; transfer with CRC works
    [controller-software.ino, sensor-software.ino]
2020-03-28 Improved mass airflow sensor code
2020-03-29 Mass airflow sensor: changed serial output for debug, added supervision pins
2020-03-29 Mass airflow sensor: improved debug output, added cycle supervision output pin
2020-03-31 Changed differential pressure to flow measurement
2020-04-04 mass airflow sensor controller: fixed some bugs, improved code
    [controller-software.ino]
